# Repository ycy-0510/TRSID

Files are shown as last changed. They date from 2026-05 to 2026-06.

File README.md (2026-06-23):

# TRSID
Tiny Raspi System information display

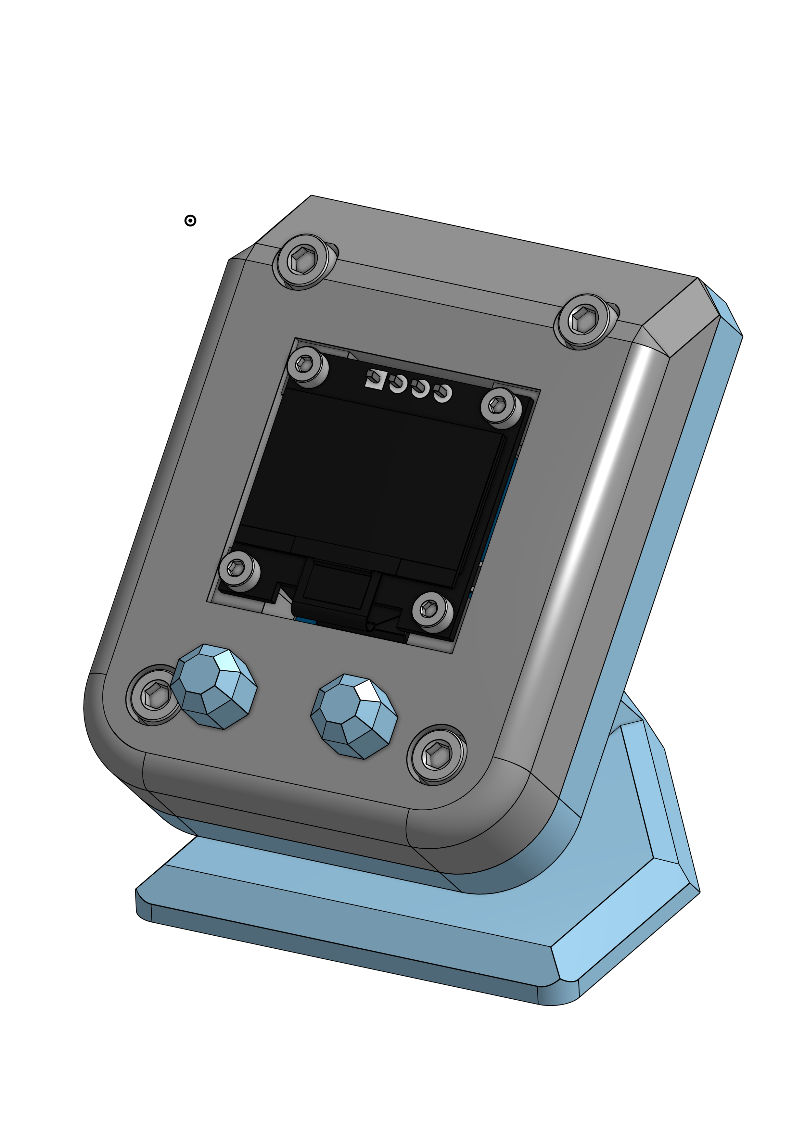
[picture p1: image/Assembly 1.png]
TRSID


## Description
This project is a tiny system information display for a Raspberry Pi.
It is powered by a WS2812 LED strip and a tiny OLED display. The system information is displayed on the OLED screen, while the LED strip provides a visual representation of the system's status.

## Features
- Displays CPU usage, memory usage, and disk usage on the OLED screen.
- Uses the WS2812 LED strip to indicate system status with different colors.
- Auto-sleep (software) when the system is idle for a certain period of time.
- Wake up by pressing a button
- Change mode by pressing a button

## PCB
The PCB is designed to be compact and efficient, with a focus on minimizing power consumption and external wiring. 

It is designed with EASYEDA, and the project link is [here](https://oshwlab.com/chengyanyang0510/project_qzuwjpkp).

### Main components
- SSD1322 OLED display
- WS2812 LED * 8
- PCF8574 I/O expander
- Button * 2

### PCB Layout
<table>
  <tr>
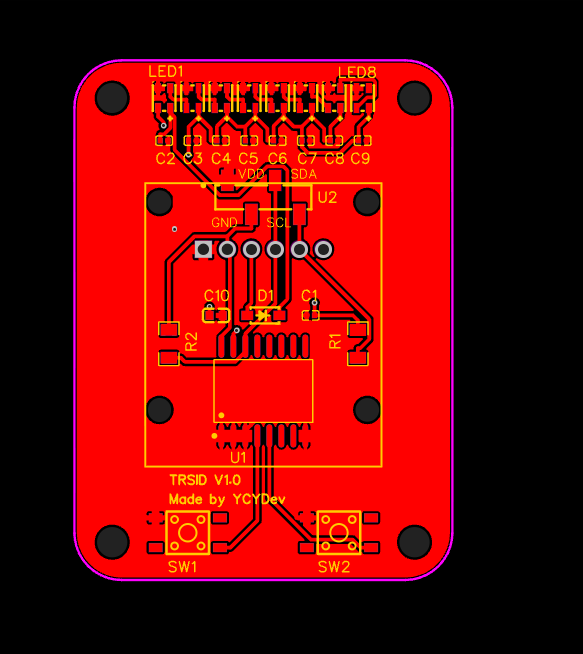
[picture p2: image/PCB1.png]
PCB Layout 1
    <td></td>
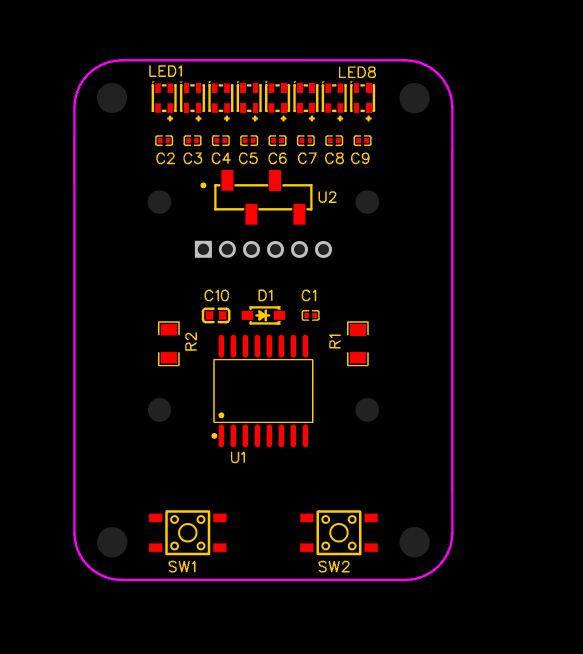
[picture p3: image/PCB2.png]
PCB Layout 2
    <td></td>
  </tr>
</table>

## Cad for 3D printing
The case for the TRSID is designed to be 3D printed. The design is simple and functional, with a focus on protecting the components while allowing easy access to the display and buttons.
### 3D Model
3D models are separately designed for the top, bottom, and support parts of the case. The top part includes cutouts for the OLED display, buttons and thin shell for the WS2812 LED strip. It also designs as housing for the PCB. The bottom part is designed to be a simple cover the top part and has a connection track for the support part. The support part is designed to make the top and bottom parts stand at a 45-degree angle, providing better visibility of the display and easier access to the buttons.

It is designed with OnShape, and the project link is [here](https://cad.onshape.com/documents/a4710ab7be3b6c054e07b878/w/2be8e1274c556d9d3fb8e346/e/1eefdb152957cf088d041770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).
<table>
    <tr>
        <td>Top Part</td>
        <td>Bottom Part</td>
        <td>Support Part</td>
    </tr>
    <tr>
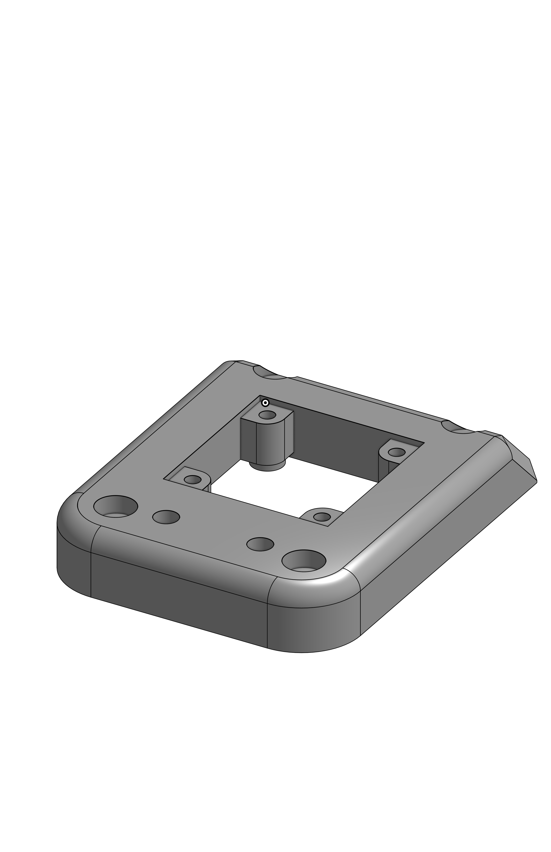
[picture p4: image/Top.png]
Top Part
        <td></td>
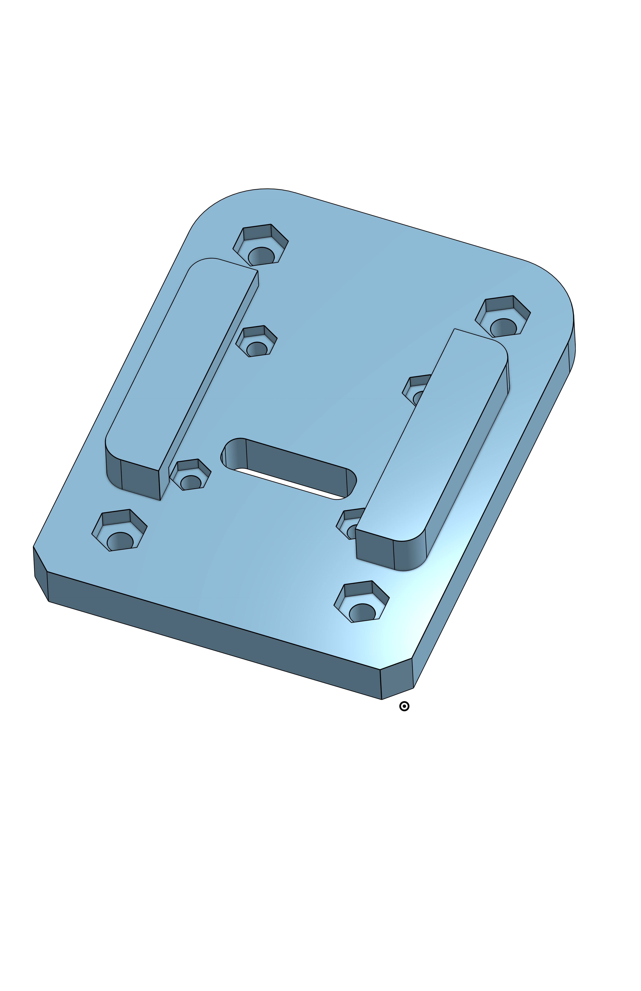
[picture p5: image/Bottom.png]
Bottom Part
        <td></td>
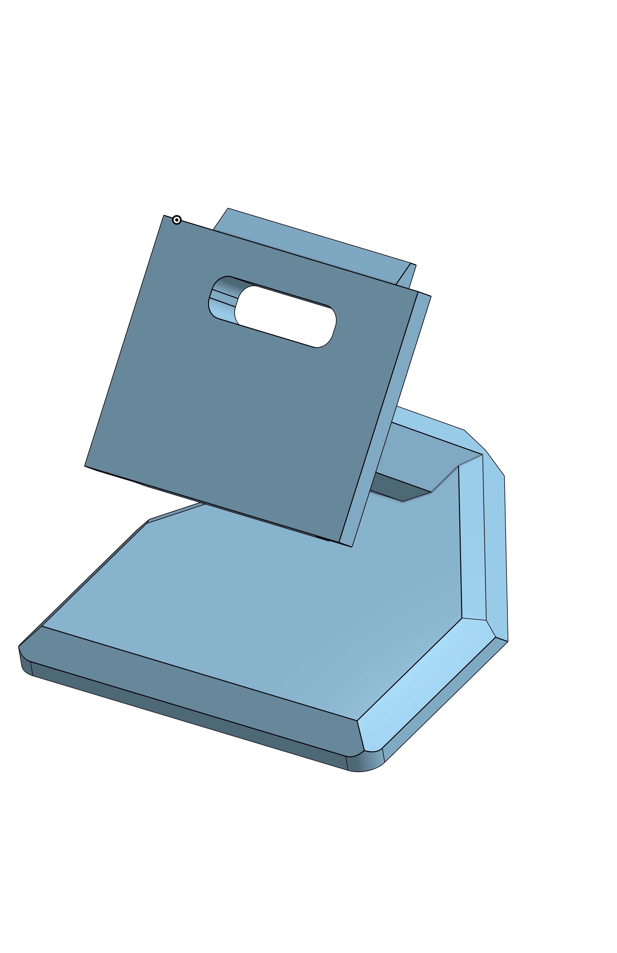
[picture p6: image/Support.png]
Support Part
        <td></td>
    </tr>
    <tr>
        <td>Button extension</td>
        <td>button extension hat</td>
        <td></td>
    </tr>
     <tr>
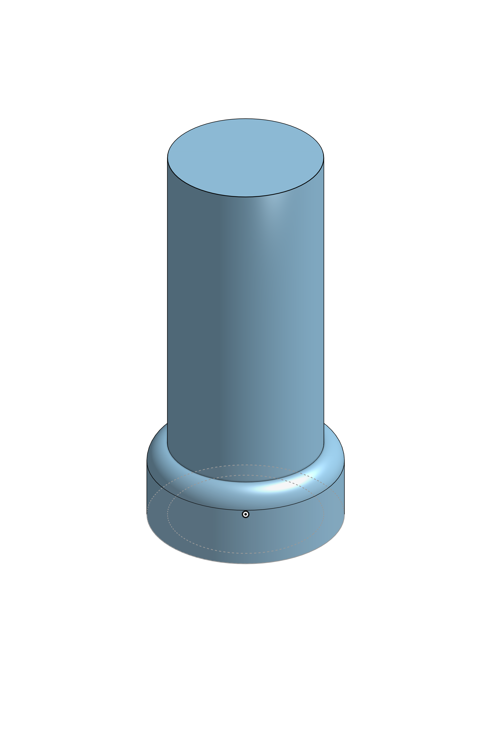
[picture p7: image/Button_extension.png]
Button Extension
        <td></td>
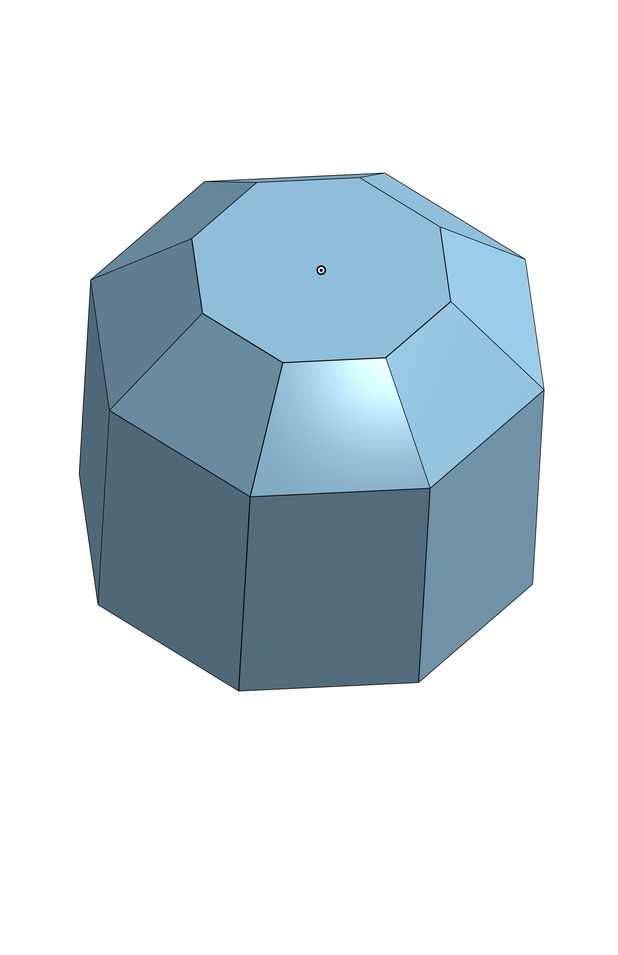
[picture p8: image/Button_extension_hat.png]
Button Extension Hat
        <td></td>
        <td></td>
    </tr>
</table>

### Screws and Hex Nuts

<table>
    <thead>
        <tr>
            <th>Type</th>
            <th>Length</th>
            <th>Quantity</th>
        </tr>
    </thead>
    <tbody>
        <tr>
            <td>M3 Screw</td>
            <td>14mm</td>
            <td>4</td>
        </tr>
        <tr>
            <td>M3 Hex Nut</td>
            <td>N/A</td>
            <td>4</td>
        </tr>
        <tr>
            <td>M2 Screw</td>
            <td>16mm</td>
            <td>4</td>
        </tr>
        <tr>
            <td>M2 Hex Nut</td>
            <td>N/A</td>
            <td>4</td>
        </tr>
    </tbody>
</table>

## Code
The code for the TRSID is written in Python and is designed to run on a Raspberry Pi. It uses the `rpi_ws281x` library to control the WS2812 LED strip and the `Adafruit_SSD1322` library to control the OLED display. The code is structured to allow for easy updates and modifications, with clear separation between the different components of the system.

### Part code
- [ws2812.py](https://raw.githubusercontent.com/ycy-0510/TRSID/main/code/part/ws2812.py): Code for controlling the WS2812 LED strip.
- [ssd1306oled.py](https://raw.githubusercontent.com/ycy-0510/TRSID/main/code/part/ssd1306oled.py): Code for controlling the OLED display.
- [pcf8574.py](https://raw.githubusercontent.com/ycy-0510/TRSID/main/code/part/pcf8574.py): Code for handling button inputs.

### Main code
- [main.py](https://raw.githubusercontent.com/ycy-0510/TRSID/main/code/main.py): Main code that integrates all components and implements the system information display functionality.

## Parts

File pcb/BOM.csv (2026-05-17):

ID | Name | Designator | Footprint | Quantity | Manufacturer Part | Manufacturer | Supplier | Supplier Part | Price | link
1 | Header-Male-2.54_1x6 | PI-GPIO | HDR-TH_6P-P2.54-V-M-1 | 1 | 2.54-1x6P直针 | BOOMELE(博穆精密) | LCSC | C37208 |  | https://item.szlcsc.com/38187.html
2 | 10uF | C10 | C0603 | 1 | CL10A106KP8NNNC | SAMSUNG(三星) | LCSC | C19702 |  | https://item.szlcsc.com/362304.html
3 | B5819W_C8598 | D1 | SOD-123_L2.7-W1.6-LS3.7-RD-1 | 1 | B5819W SL | CJ(江苏长电/长晶) | LCSC | C8598 |  | https://atta.szlcsc.com/upload/public/pdf/source/20210423/C2828417_EF1BF8BE3D48F97E320B09B073C89160.pdf
4 | WS2812C-2427 | LED1,LED2,LED3,LED4,LED5,LED6,LED7,LED8 | LED-SMD_4P-L2.7-W2.4-TL_WS2812C-2427 | 8 | WS2812C-2427 | worldsemi | LCSC | C4154872 |  | https://atta.szlcsc.com/upload/public/pdf/source/20220711/31649AD10DC92AC81DB783DA7EDB52A8.pdf
5 | 100nF | C2,C3,C4,C5,C6,C7,C8,C9,C1 | C0402 | 9 | CL05B104KO5NNNC | SAMSUNG(三星) | LCSC | C1525 |  | https://item.szlcsc.com/15869.html
6 | 4.5X4.5X4.3WATERPROOF TACT SWITCH SMT 260G | SW1,SW2 | SW-SMD_4P-L4.5-W4.5-P3.15-LS7.5-TL | 2 | 4.5x4.5x4.3Waterproof Tact Switch SMT 260g | CAX(创都) | LCSC | C39832244 |  | https://atta.szlcsc.com/upload/public/pdf/source/20240809/8525B349B1F98FF676DFFF5BD15A6D81.pdf
7 | HX PM2.54-1X4P TP-YQ | U2 | HDR-SMD_HX-PM2.54-1X4P-TP-YQ | 1 | HX PM2.54-1x4P TP-YQ | hanxia(韩下) | LCSC | C42379197 |  | https://atta.szlcsc.com/upload/public/pdf/source/20241108/3345CEE45683BD4F7E002554BF8D3126.pdf
8 | 10kΩ | R1,R2 | R1206 | 2 | 1206W4F1002T5E | UNI-ROYAL(厚声) | LCSC | C17902 |  | https://item.szlcsc.com/311874.html
9 | PCF8574WS16ARAE | U1 | SOP-16_L10.3-W7.5-P1.27-LS10.3-BL | 1 | PCF8574WS16ARAE | GR(国睿) | LCSC | C49443602 |  | https://pdf1.alldatasheet.com/datasheet-pdf/view/1244756/MCNIX/MX25L6433FMI-08G.html

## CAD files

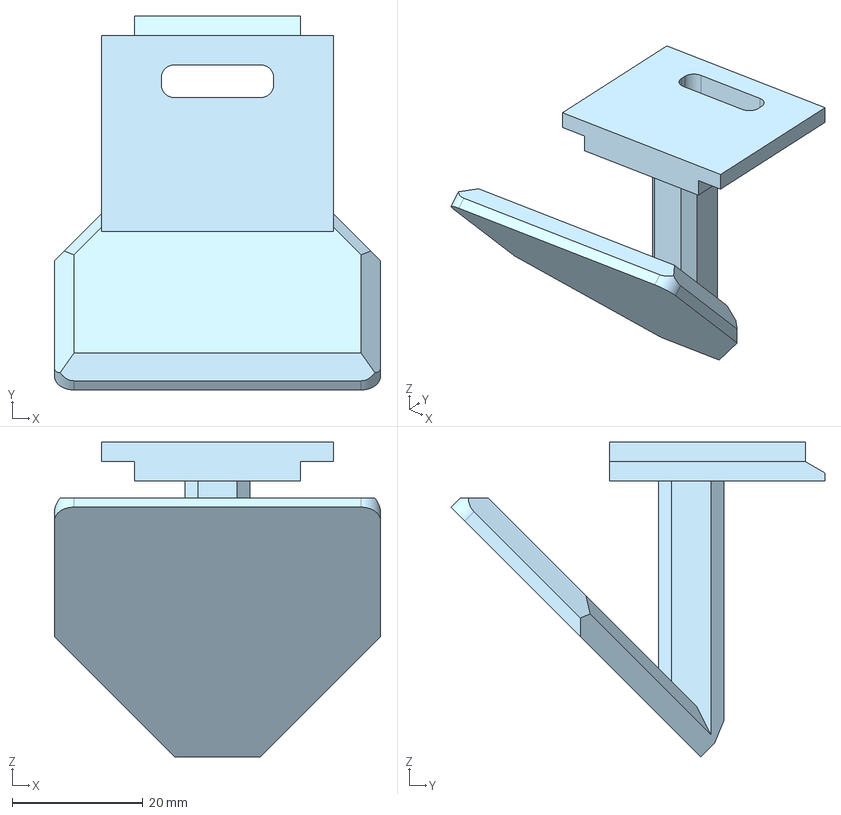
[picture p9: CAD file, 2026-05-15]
cad/Support.step
50.0 x 57.3 x 48.2 mm

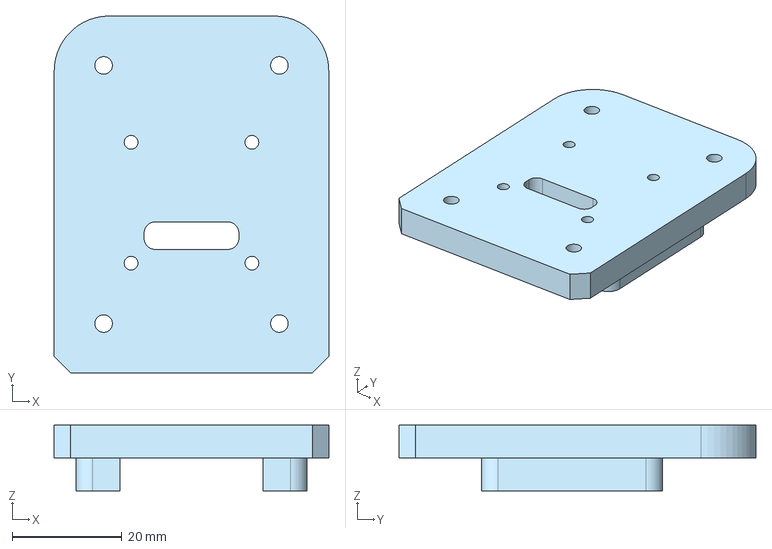
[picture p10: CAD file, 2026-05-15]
cad/Bottom.step
50.0 x 65.0 x 12.0 mm

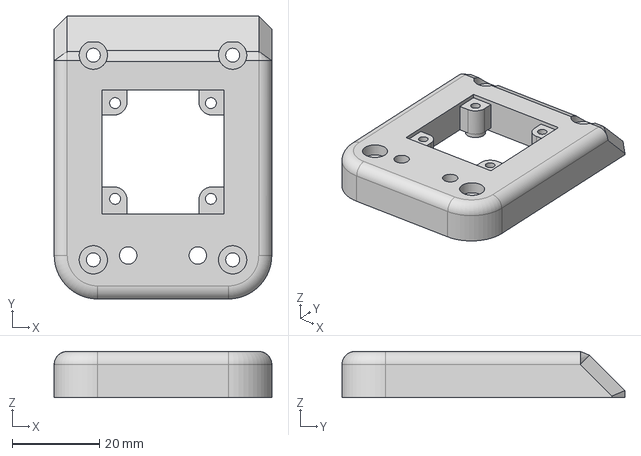
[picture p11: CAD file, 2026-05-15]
cad/Top.step
50.0 x 65.0 x 10.6 mm

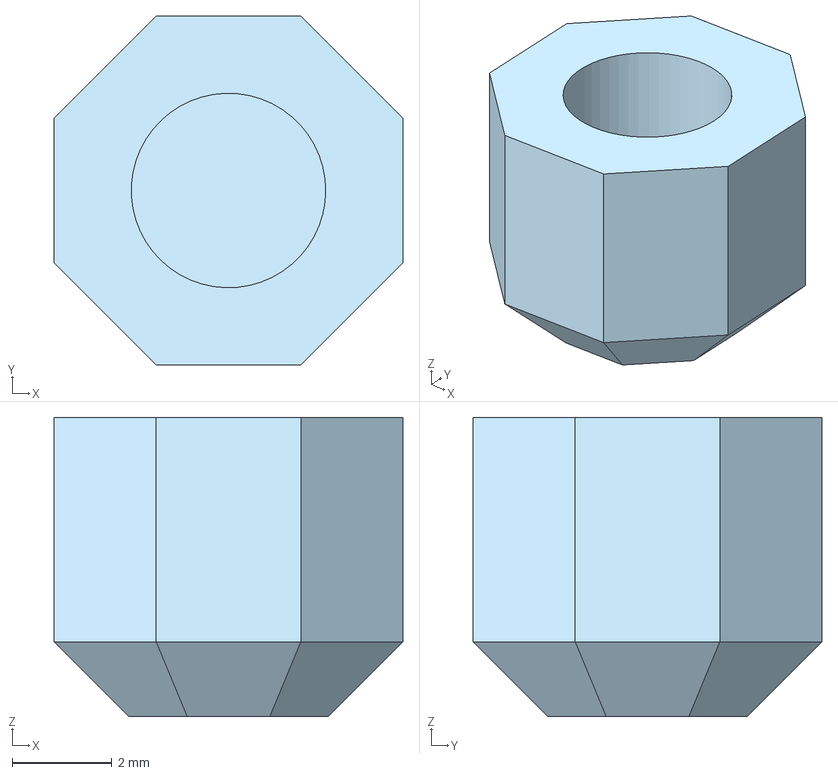
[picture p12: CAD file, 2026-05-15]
cad/Button.step
7.00 x 7.00 x 6.00 mm

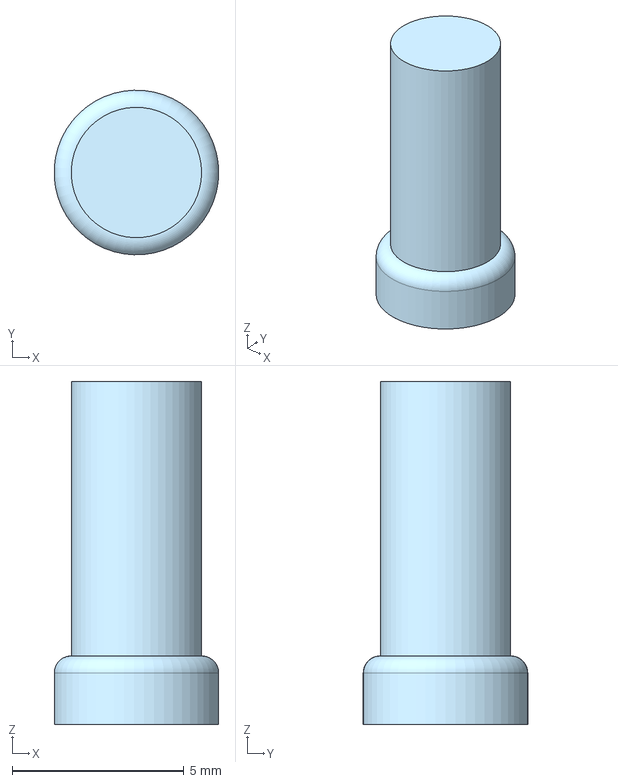
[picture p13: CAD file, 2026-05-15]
cad/Button extension.step
4.80 x 4.80 x 10.0 mm

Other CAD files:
cad/Bottom.stl
cad/Button extension.stl
cad/Button.stl
cad/Support.stl
cad/Top.stl

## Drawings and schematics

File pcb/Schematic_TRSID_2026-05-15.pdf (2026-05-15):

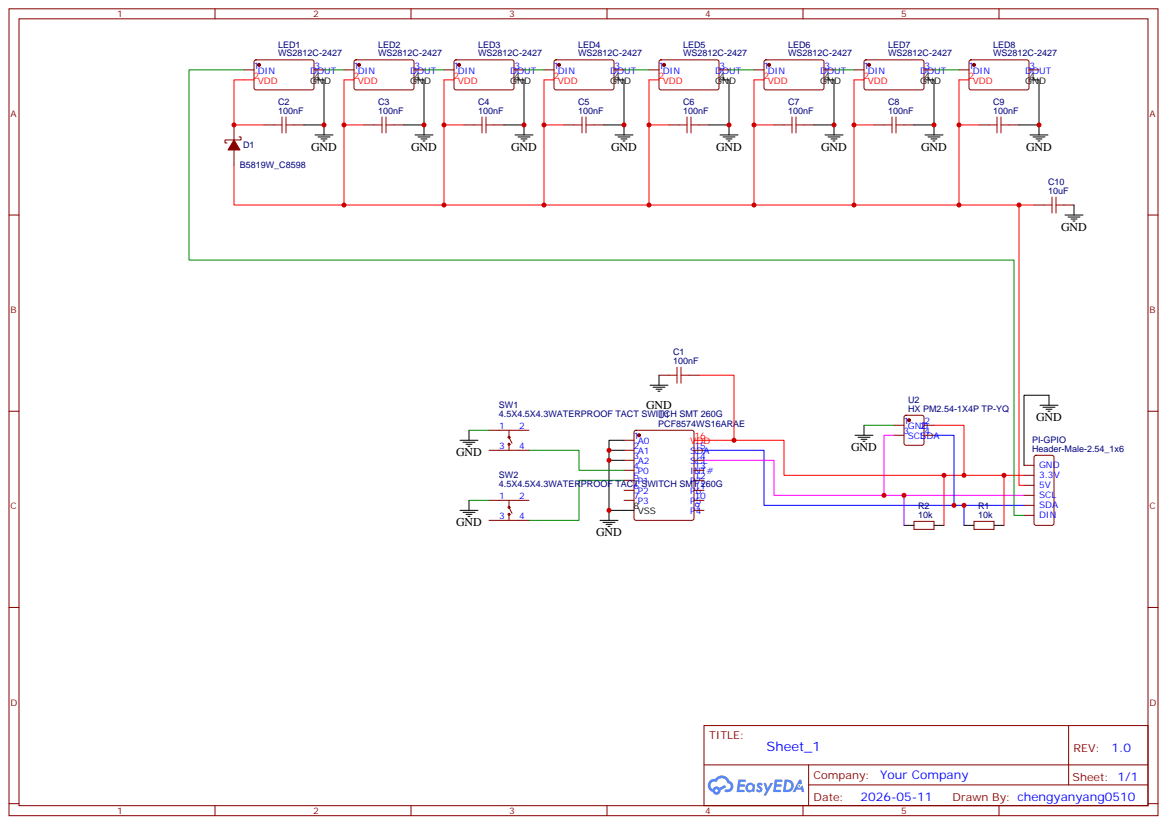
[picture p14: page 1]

P510 P611 P712 INT# 13 SCL 14 SDA 15 VDD 16

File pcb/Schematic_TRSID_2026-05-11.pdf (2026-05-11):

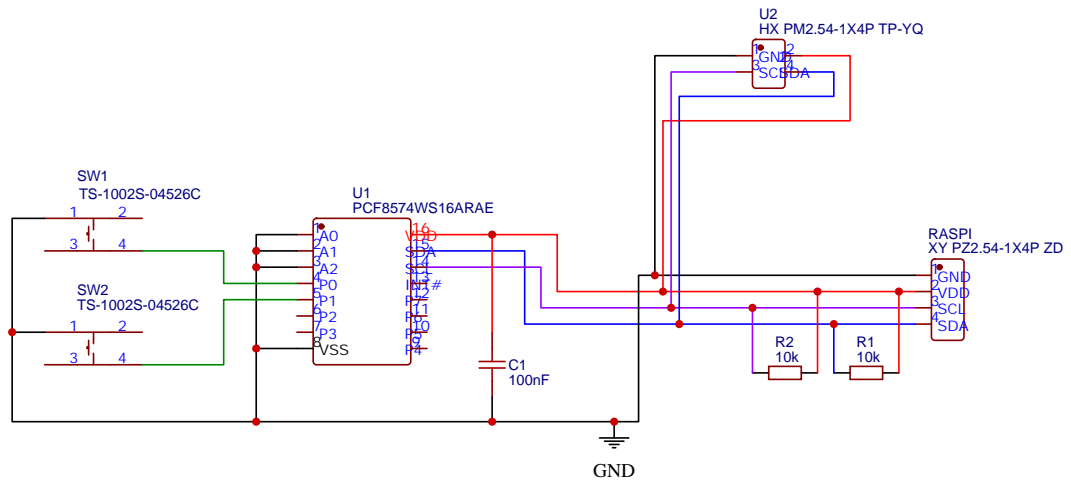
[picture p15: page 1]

P510 P611 P712 INT# 13 SCL 14 SDA 15 VDD 16

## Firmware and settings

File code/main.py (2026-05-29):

import time
import board
import neopixel
import busio
import adafruit_ssd1306
from smbus2 import SMBus
import psutil
import os
import glob
from PIL import Image,ImageDraw,ImageFont

OLED_ADDR = 0x3C

I2C_BUS = 1
PCF8574_ADDR = 0x20
SW1_ADDR = 0x01
SW2_ADDR = 0x02

PIXEL_PIN = board.D18
NUM_PIXELS = 8
ORDER = neopixel.GRB

i2c = busio.I2C(board.SCL, board.SDA)

oled = adafruit_ssd1306.SSD1306_I2C(128, 64, i2c, addr=OLED_ADDR)

bus = SMBus(I2C_BUS)

pixels = neopixel.NeoPixel(
    PIXEL_PIN,
    NUM_PIXELS,
    brightness=0.5,  # 0.0 to 1.0
    auto_write=False,  # Update by function show()
    pixel_order=ORDER,
)

t = 5


def get_cpu_info() -> str:
    """Get CPU model information from /proc/cpuinfo."""
    if os.path.exists("/proc/cpuinfo"):
        with open("/proc/cpuinfo") as f:
            for line in f:
                if "Model" in line or "hardware" in line.lower():
                    return line.split(":")[1].strip()
    return "Unknown CPU"


def get_cpu_usage() -> dict:
    """Get current CPU usage percentage and core count.

    Uses interval=None (non-blocking): returns usage since the previous call,
    so the polling loop is never stalled. Prime it once at startup.
    """
    return {
        "cpu_percent": psutil.cpu_percent(interval=None),
        "cpu_core": psutil.cpu_count(logical=True),
    }


def get_ram_info() -> dict:
    """Get RAM usage information."""
    mem = psutil.virtual_memory()
    return {
        "total_md": mem.total / (1024**2),
        "used_md": mem.used / (1024**2),
        "free_md": mem.free / (1024**2),
        "percent": mem.percent,
    }


def get_disk_info() -> list[dict]:
    """Get disk partitions and their usage information."""
    partitions_info = []
    partitions = psutil.disk_partitions()
    for partition in partitions:
        if "loop" in partition.device or not partition.mountpoint:
            continue
        try:
            usage = psutil.disk_usage(partition.mountpoint)
            partitions_info.append(
                {
                    "device": partition.device,
                    "mountpoint": partition.mountpoint,
                    "fstype": partition.fstype,
                    "total_gb": usage.total / (1024**3),
                    "used_gb": usage.used / (1024**3),
                    "free_gb": usage.free / (1024**3),
                    "percent": usage.percent,
                }
            )
        except PermissionError:
            continue
    return partitions_info


def get_temperature() -> float | None:
    """Read CPU temperature from the system thermal interface."""
    path = "/sys/class/thermal/thermal_zone0/temp"
    if os.path.exists(path):
        with open(path) as f:
            temp_raw = int(f.read().strip())
            return temp_raw / 1000.0
    return None


def get_fan_speed() -> int | None:
    """Read fan speed (RPM) from the kernel hwmon interface."""

    for path in glob.glob("/sys/class/hwmon/hwmon*/fan*_input"):
        try:
            with open(path) as f:
                return int(f.read().strip())
        except (OSError, ValueError):
            continue
    return None


def get_switch_state() -> tuple[bool, bool]:
    """Read the state of two switches connected to the PCF8574."""
    data = bus.read_byte(PCF8574_ADDR)
    sw1 = not (data & SW1_ADDR)
    sw2 = not (data & SW2_ADDR)
    return sw1, sw2


class State:
    def __init__(self):
        self.cpu_info: str = ""
        self.cpu_usage: dict = {}
        self.ram_info: dict = {}
        self.disk_info: list = []
        self.temperature: float | None = None
        self.fan_speed: int | None = None
        self.page = 0
        self.start_time = time.time()


state = State()


def display_info():
    oled.fill(0)
    image = Image.new("1", (128, 64))
    draw = ImageDraw.Draw(image)
    match state.page:
        case -1:
            pass
        case 0:
            # Add CPU image on the left side (0,0) to (32,32)
            icon = Image.open("../assets/cpu.png").resize((32, 32)).convert("1")
            image.paste(icon, (0, 0))
            # Add CPU info text on the right side
            font = ImageFont.load_default()
            draw.text((34, 0), f"CPU: {state.cpu_info}", font=font, fill=255)
            draw.text((34, 10), f"Usage: {state.cpu_usage.get('cpu_percent', 0)}%", font=font, fill=255)
            draw.text((34, 20), f"Cores: {state.cpu_usage.get('cpu_core', 0)}", font=font, fill=255)
        case 1:
            # Add RAM image on the left side (0,0) to (32,32)
            icon = Image.open("../assets/ram.png").resize((32, 32)).convert("1")
            image.paste(icon, (0, 0))
            # Add RAM info text on the right side
            font = ImageFont.load_default()
            draw.text((34, 0), f"RAM Total: {state.ram_info.get('total_md', 0):.1f}MB", font=font, fill=255)
            draw.text((34, 10), f"Used: {state.ram_info.get('used_md', 0):.1f}MB", font=font, fill=255)
            draw.text((34, 20), f"Free: {state.ram_info.get('free_md', 0):.1f}MB", font=font, fill=255)
            draw.text((34, 30), f"Usage: {state.ram_info.get('percent', 0)}%", font=font, fill=255)
        case 2:
            # Add Disk image on the left side (0,0) to (32,32)
            icon = Image.open("../assets/disk.png").resize((32, 32)).convert("1")
            image.paste(icon, (0, 0))
            # Add Disk info text on the right side
            font = ImageFont.load_default()
            if state.disk_info:
                disk = state.disk_info[0]  # Show info for the first disk only
                draw.text((34, 0), f"Disk: {disk['device']}", font=font, fill=255)
                draw.text((34, 10), f"Mount: {disk['mountpoint']}", font=font, fill=255)
                draw.text((34, 20), f"Used: {disk['used_gb']:.1f}GB", font=font, fill=255)
                draw.text((34, 30), f"Free: {disk['free_gb']:.1f}GB", font=font, fill=255)
                draw.text((34, 40), f"Usage: {disk['percent']}%", font=font, fill=255)
            else:
                draw.text((34, 0), "No disk info", font=font, fill=255)
        case 3:
            # Add Temperature image on the left side (0,0) to (32,32)
            icon = Image.open("../assets/temp.png").resize((32, 32)).convert("1")
            image.paste(icon, (0, 0))
            # Add Temperature info text on the right side
            font = ImageFont.load_default()
            if state.temperature is not None:
                draw.text((34, 0), f"Temp: {state.temperature:.1f}°C", font=font, fill=255)
            else:
                draw.text((34, 0), "No temp info", font=font, fill=255)
        case 4:
            # Add Fan image on the left side (0,0) to (32,32)
            icon = Image.open("../assets/fan.png").resize((32, 32)).convert("1")
            image.paste(icon, (0, 0))
            # Add Fan info text on the right side
            font = ImageFont.load_default()
            if state.fan_speed is not None:
                draw.text((34, 0), f"Fan Speed: {state.fan_speed}", font=font, fill=255)
            else:
                draw.text((34, 0), "No fan info", font=font, fill=255)
    oled.image(image)
    oled.show()
    


def _level_color(pct: float) -> tuple[int, int, int]:
    """Map a 0-100 level onto green (low) -> yellow (mid) -> red (high)."""
    if pct < 50:
        return (0, 255, 0)
    if pct < 80:
        return (255, 255, 0)
    return (255, 0, 0)


_last_leds: list[tuple[int, int, int]] | None = None


def control_ws2812():
    """Show the active page's metric as a color bar across the 8 LEDs."""
    # Sleep mode: all LEDs off.
    if state.page == -1:
        pct = 0.0
    else:
        match state.page:
            case 0:
                pct = state.cpu_usage.get("cpu_percent", 0)
            case 1:
                pct = state.ram_info.get("percent", 0)
            case 2:
                pct = state.disk_info[0]["percent"] if state.disk_info else 0
            case 3:
                # Map 30-85 °C onto 0-100 %.
                pct = ((state.temperature or 0) - 30) / (85 - 30) * 100
            case 4:
                # Map 0-8000 RPM onto 0-100 %.
                pct = (state.fan_speed or 0) / 8000 * 100
            case _:
                pct = 0

    pct = max(0.0, min(100.0, float(pct)))
    lit = round(pct / 100 * NUM_PIXELS)
    color = _level_color(pct)
    leds = [color if i < lit else (0, 0, 0) for i in range(NUM_PIXELS)]

    global _last_leds
    if leds == _last_leds:
        return
    _last_leds = leds
    for i, c in enumerate(leds):
        pixels[i] = c
    pixels.show()


SWITCH_INTERVAL = 0.02
REFRESH_INTERVAL = 0.5
PAGE_COUNT = 5
AUTO_ADVANCE = 5


def handle_switches(prev_sw1: bool, prev_sw2: bool) -> tuple[bool, bool, bool]:
    """Poll switches, acting only on the rising edge (press, not hold).

    Returns the current (sw1, sw2) states plus whether the page changed.
    """
    sw1, sw2 = get_switch_state()
    changed = False
    if sw1 and not prev_sw1:  # SW1: toggle sleep mode
        state.page = -1 if state.page != -1 else 0
        state.start_time = time.time()
        changed = True
    if sw2 and not prev_sw2:  # SW2: next page
        state.page = (state.page + 1) % PAGE_COUNT
        state.start_time = time.time()
        changed = True
    return sw1, sw2, changed


def refresh():
    """Fetch data for the active page and update the OLED + LEDs."""
    # Auto-advance to the next page after AUTO_ADVANCE seconds (unless sleeping).
    if state.page != -1 and time.time() - state.start_time >= AUTO_ADVANCE:
        state.start_time = time.time()
        state.page = (state.page + 1) % PAGE_COUNT

    match state.page:
        case 0:
            state.cpu_info = get_cpu_info()
            state.cpu_usage = get_cpu_usage()
        case 1:
            state.ram_info = get_ram_info()
        case 2:
            state.disk_info = get_disk_info()
        case 3:
            state.temperature = get_temperature()
        case 4:
            state.fan_speed = get_fan_speed()

    display_info()
    control_ws2812()


def run():
    prev_sw1 = prev_sw2 = False
    last_refresh = 0.0
    while True:
        prev_sw1, prev_sw2, changed = handle_switches(prev_sw1, prev_sw2)
        now = time.time()
        # Refresh on schedule, or immediately when a button changed the page.
        if changed or now - last_refresh >= REFRESH_INTERVAL:
            last_refresh = now
            refresh()
        time.sleep(SWITCH_INTERVAL)


def main():
    bus.write_byte(PCF8574_ADDR, 0x00)
    oled.fill(0)
    oled.show()
    pixels.fill((0, 0, 0))
    pixels.show()
    psutil.cpu_percent(interval=None)  # prime non-blocking CPU usage
    try:
        run()
    except KeyboardInterrupt:
        oled.fill(0)
        oled.show()
        pixels.fill((0, 0, 0))
        pixels.show()
        bus.close()
        print("Stopped by user.")


if __name__ == "__main__":
    main()

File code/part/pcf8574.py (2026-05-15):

import time
from smbus2 import SMBus

I2C_BUS = 1
PCF8574_ADDR = 0x20
SW1_ADDR = 0x01
SW2_ADDR = 0x02

bus = SMBus(I2C_BUS)

try:
    bus.write_byte(PCF8574_ADDR, 0x00) # 0x00 = 111 1111, all pins high
    print("Start reading PCF8574...")
    while True:
        data = bus.read_byte(PCF8574_ADDR)
        sw1 = not (data & SW1_ADDR)  # SW1 is connected to P0
        sw2 = not (data & SW2_ADDR)  # SW2 is connected to P1
        print(f'Raw: {bin(data):>10} | SW1: {sw1}, SW2: {sw2}') # :>10 for right-aligning the binary output
        time.sleep(0.2)
except KeyboardInterrupt:
    bus.close()
    print("Stopped by user.")

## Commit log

2026-05-15 Update PCB and Cad
    [Bottom.step, Bottom.stl, Button extension.step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]
2026-05-15 Update support cad
    [Support.step, Support.stl]
2026-05-17 Add BOM
    [BOM.csv]
2026-06-11 feat: add epro pcb file
